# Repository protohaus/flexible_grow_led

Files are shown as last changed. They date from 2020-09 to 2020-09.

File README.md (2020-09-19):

# Flexible Grow LED

This project is the result of Sören Krusche's student research project.
The aim was to create a flexible LED light for growing plants with adjustable wavelengths.
It encompases the CAD files for the electronics and 3D printed components as well as the source code for the ESP8266 and the Node-RED flow.

## Node-RED Dashboard

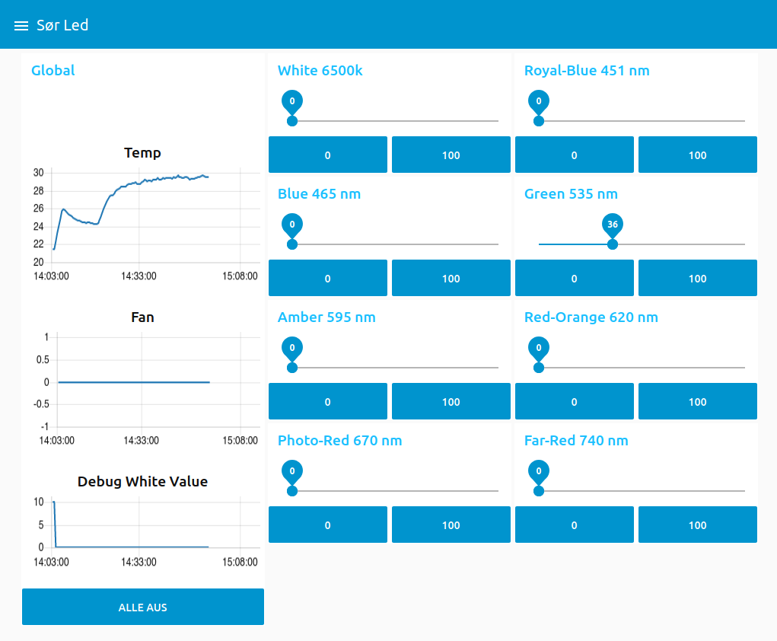
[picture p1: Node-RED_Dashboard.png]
Node-RED Dashboard


The flow can be found in the Node-RED_Flow folder.

## PCB Design

Insert PCB image

The design files can be found in the CAD/EAGLE folder.

## 3D Printed Model

Insert 3D printed model

The design files can be found in the CAD/Fusion360 folder.

## PlatformIO Project

The source code for the ESP8266 can be found in the PlatformIO folder.

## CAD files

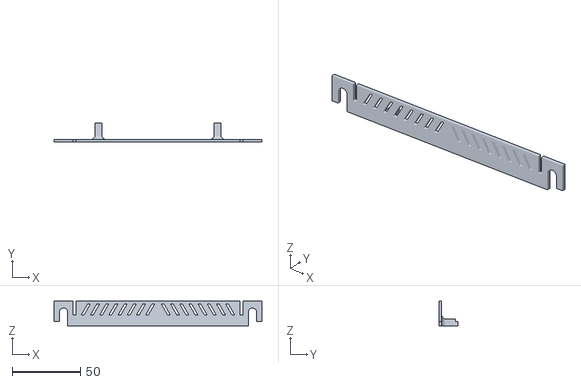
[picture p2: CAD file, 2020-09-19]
CAD/Fusion360/Halter_Back.stl
152.0 x 14.0 x 18.0

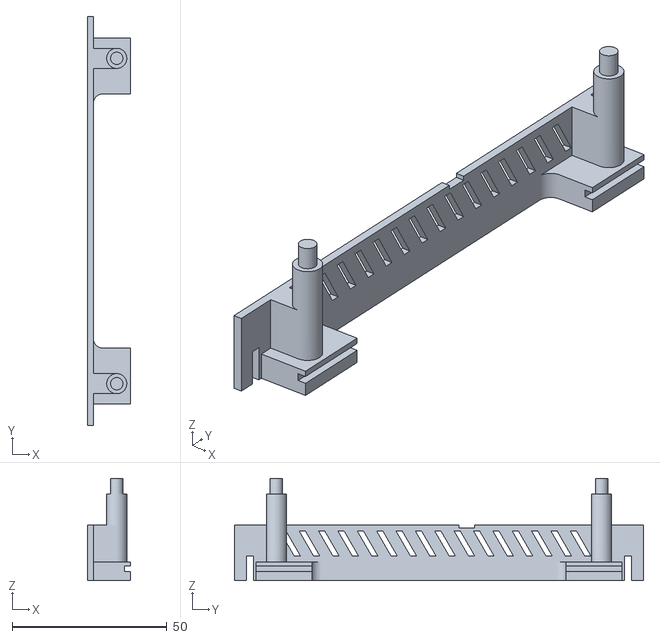
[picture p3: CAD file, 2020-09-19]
CAD/Fusion360/Halter_Right.stl
14.0 x 132.0 x 33.0

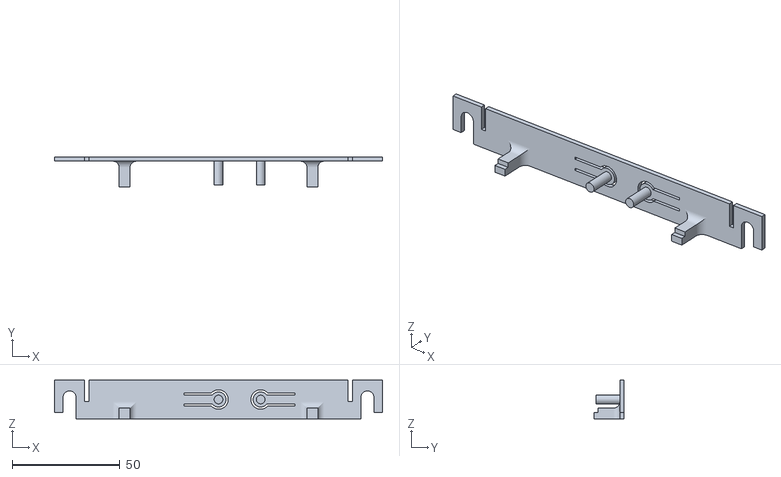
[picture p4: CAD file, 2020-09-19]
CAD/Fusion360/Halter_Front.stl
152.0 x 14.0 x 18.0

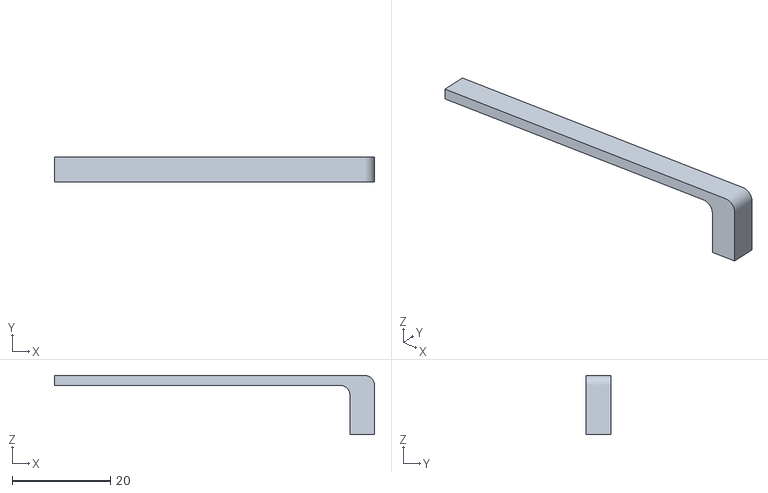
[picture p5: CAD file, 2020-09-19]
CAD/Fusion360/Lichtleiter.stl
65.0 x 5.00 x 12.0

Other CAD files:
CAD/Fusion360/Halter_Left.stl
CAD/Fusion360/Abdeckung v3.f3z
CAD/Fusion360/Halterung v11.f3z

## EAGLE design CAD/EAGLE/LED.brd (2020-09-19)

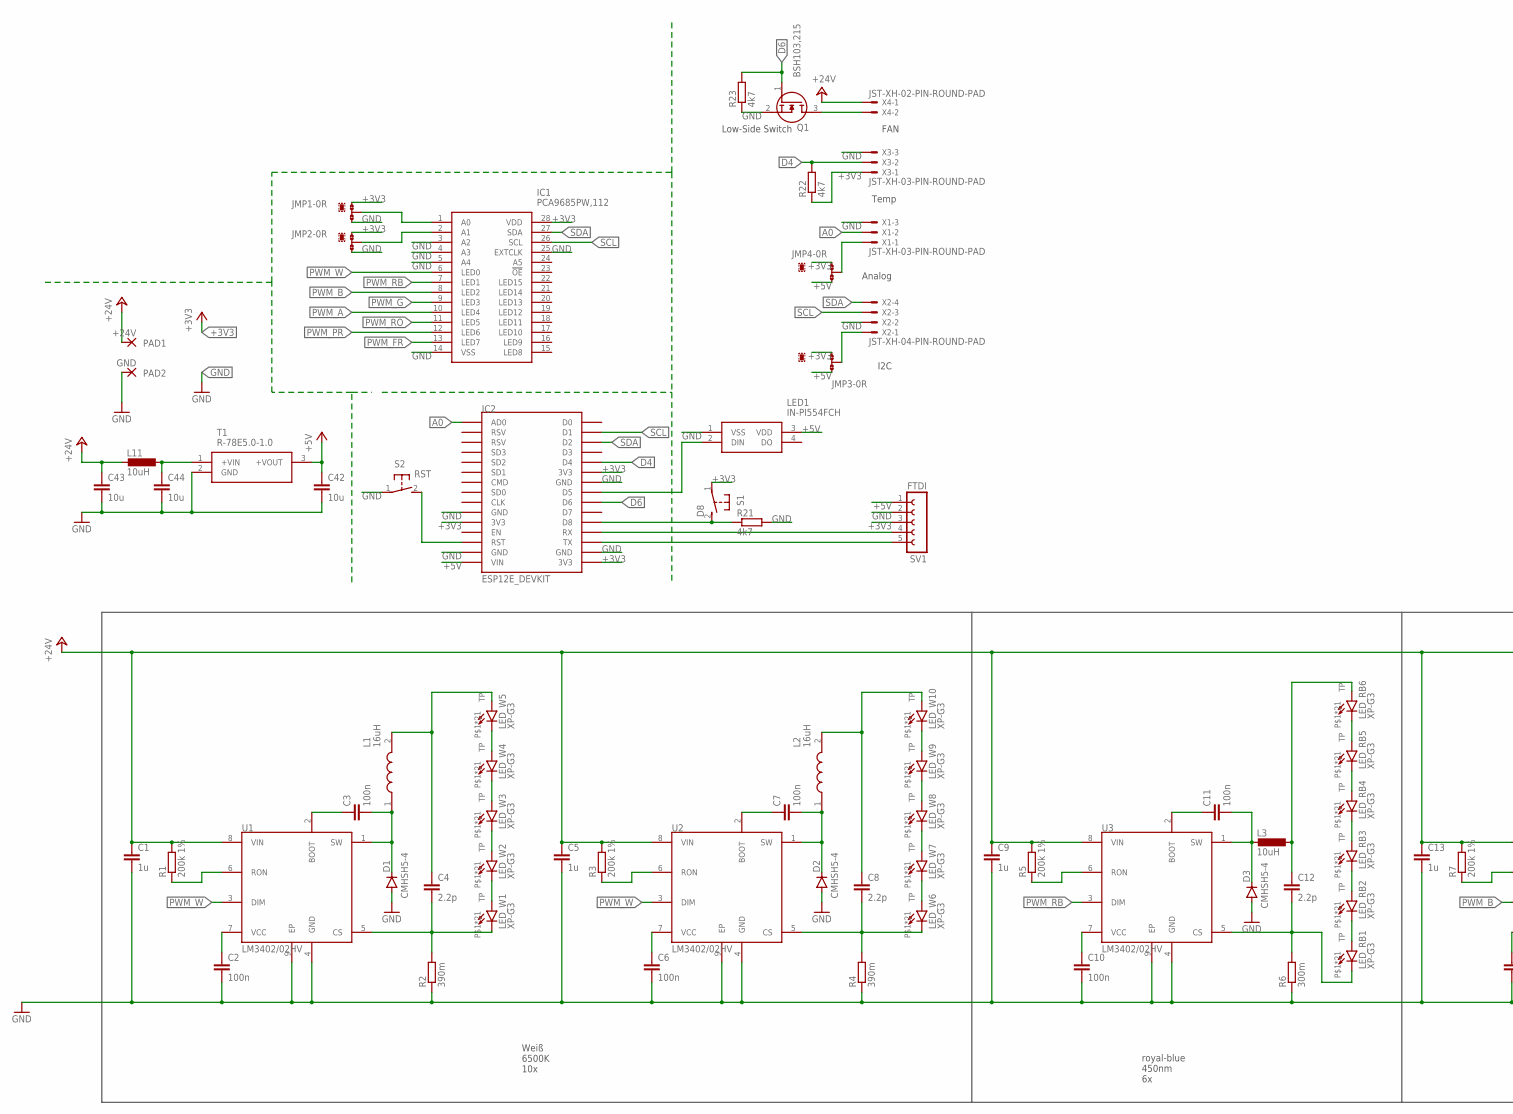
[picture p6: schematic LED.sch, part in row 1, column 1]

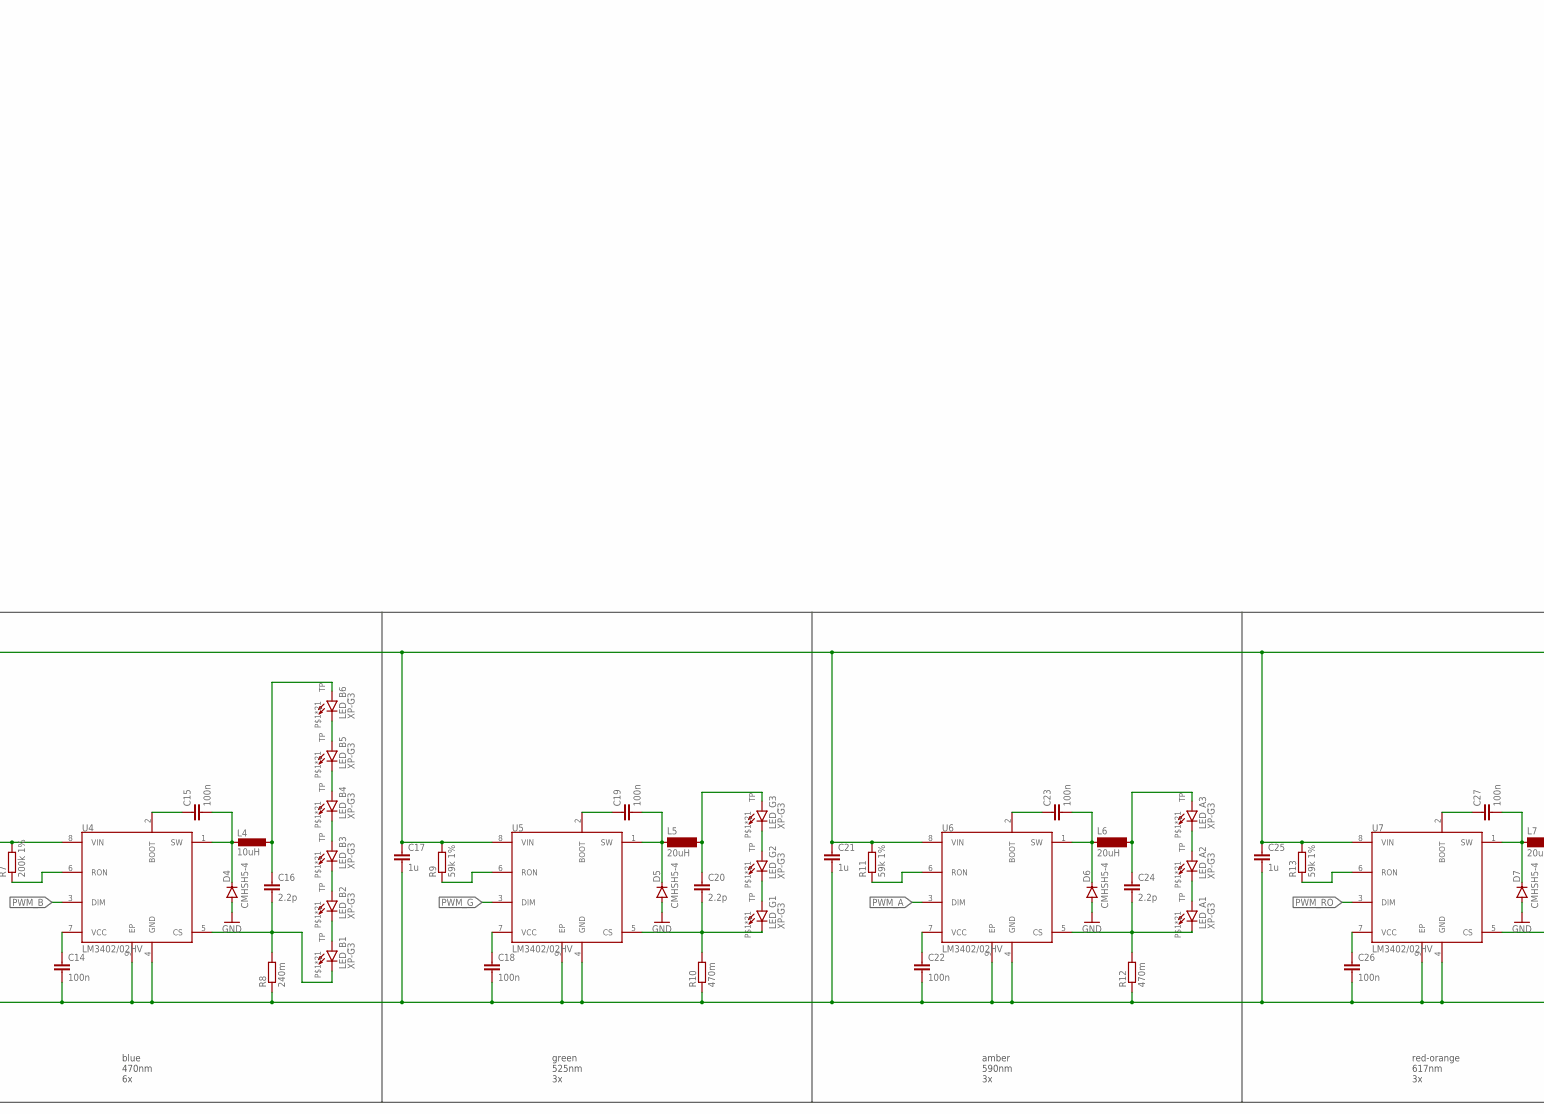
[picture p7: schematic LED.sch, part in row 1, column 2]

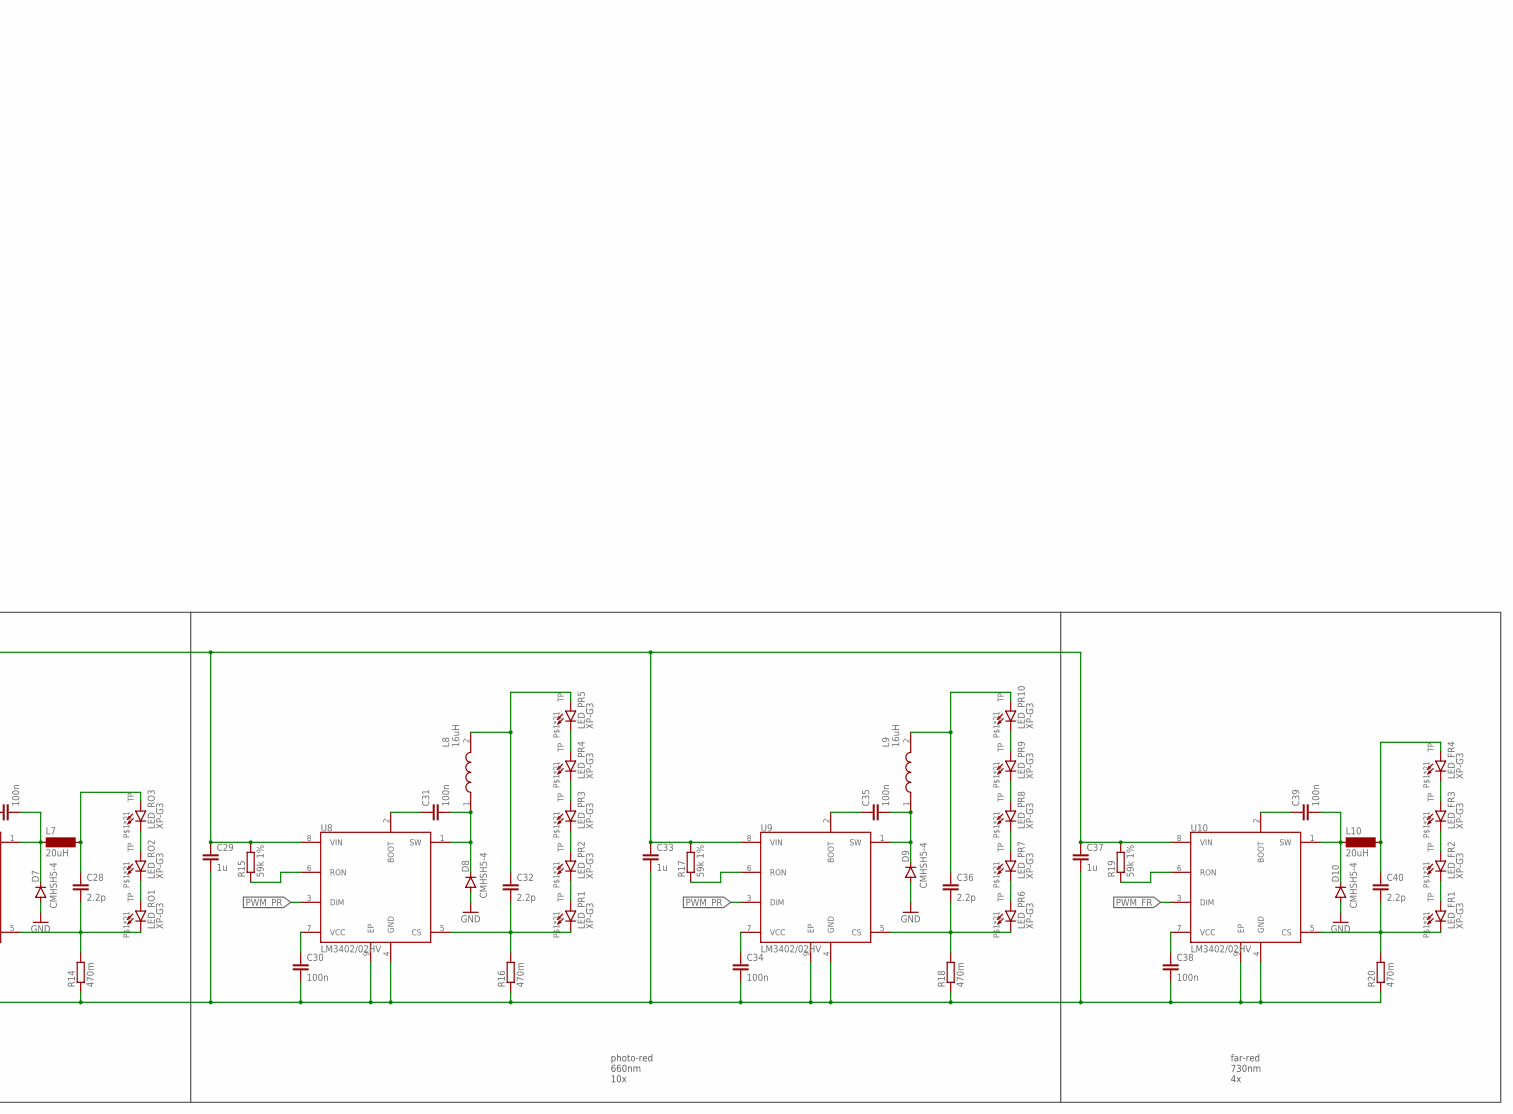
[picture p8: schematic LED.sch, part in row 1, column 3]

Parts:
C1, C5, C9, C13, C17, C21, C25, C29, C33, C37: 1u; C1206
C2, C3, C6, C7, C10, C11, C14, C15, C18, C19, C22, C23, C26, C27, C30, C31, C34, C35, C38, C39: 100n; C0805
C4, C8, C12, C16, C20, C24, C28, C32, C36, C40: 2.2p; C1206
C42, C43, C44: 10u; C1210
D1, D2, D3, D4, D5, D6, D7, D8, D9, D10: CMHSH5-4; SOD123
IC1: PCA9685PW,112; SOP65P640X110-28N
IC2: ESP12E_DEVKIT
JMP1, JMP2, JMP3, JMP4: 0R-JUMPA; A0R-JMP
L1, L2, L8, L9: 16uH; INDPM101101X680N
L3, L4, L11: 10uH; L3225M
L5, L6, L7, L10: 20uH; PF0382.223NLT
LED1: IN-PI554FCH; INPI554FCH
LED_A1, LED_A2, LED_A3: XP-G3; CREE_XLAMP
LED_B1, LED_B2, LED_B3, LED_B4, LED_B5, LED_B6: XP-G3; CREE_XLAMP
LED_FR1, LED_FR2, LED_FR3, LED_FR4: XP-G3; CREE_XLAMP
LED_G1, LED_G2, LED_G3: XP-G3; CREE_XLAMP
LED_PR1, LED_PR2, LED_PR3, LED_PR4, LED_PR5, LED_PR6, LED_PR7, LED_PR8, LED_PR9, LED_PR10: XP-G3; CREE_XLAMP
LED_RB1, LED_RB2, LED_RB3, LED_RB4, LED_RB5, LED_RB6: XP-G3; CREE_XLAMP
LED_RO1, LED_RO2, LED_RO3: XP-G3; CREE_XLAMP
LED_W1, LED_W2, LED_W3, LED_W4, LED_W5, LED_W6, LED_W7, LED_W8, LED_W9, LED_W10: XP-G3; CREE_XLAMP
PAD1: +24V; 3,81/1,4
PAD2: GND; 3,81/1,4
Q1: BSH103,215; SOT95P230X110-3N
R1, R3, R5, R7: 200k 1%; R0805
R2, R4: 390m; R0805
R6: 300m; R0805
R8: 240m; R0805
R9, R11, R13, R15, R17, R19: 59k 1%; R0805
R10, R12, R14, R16, R18, R20: 470m; R0805
R21, R22, R23: 4k7; R0805
S1: D8; B3F-31XX
S2: RST; B3F-31XX
SV1: FTDI; FE05-1
T1: R-78E5.0-1.0
U1, U2, U3, U4, U5, U6, U7, U8, U9, U10: LM3402/02HV; SOIC127P600X170-9T228N
X1, X3: JST-XH-03-PIN-ROUND-PAD; JST-XH-03-PACKAGE-ROUND-PAD
X2: JST-XH-04-PIN-ROUND-PAD; JST-XH-04-PACKAGE-ROUND-PAD
X4: JST-XH-02-PIN-ROUND-PAD; JST-XH-02-PACKAGE-ROUND-PAD

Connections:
+3V3: IC1.28 (VDD), IC2.3V3@0 (3V3), IC2.3V3@1 (3V3), IC2.3V3@2 (3V3), JMP1.1, JMP2.1, JMP3.1, JMP4.1, R22.1, S1.1, SV1.3, X3.1
+5V: C42.1, IC2.VIN, JMP3.3, JMP4.3, LED1.3 (VDD), SV1.1, T1.3 (+VOUT)
+24V: C1.1, C5.1, C9.1, C13.1, C17.1, C21.1, C25.1, C29.1, C33.1, C37.1, C43.1, L11.2, PAD1.1, R1.2, R3.2, R5.2, R7.2, R9.2, R11.2, R13.2, R15.2, R17.2, R19.2, U1.8 (VIN), U2.8 (VIN), U3.8 (VIN), U4.8 (VIN), U5.8 (VIN), U6.8 (VIN), U7.8 (VIN), U8.8 (VIN), U9.8 (VIN), U10.8 (VIN), X4.1
A0: IC2.AD0, X1.2
D4: IC2.D4, R22.2, X3.2
D6: IC2.D6, Q1.1 (G), R23.2
GND: C1.2, C2.2, C5.2, C6.2, C9.2, C10.2, C13.2, C14.2, C17.2, C18.2, C21.2, C22.2, C25.2, C26.2, C29.2, C30.2, C33.2, C34.2, C37.2, C38.2, C42.2, C43.2, C44.2, D1.A, D2.A, D3.A, D4.A, D5.A, D6.A, D7.A, D8.A, D9.A, D10.A, IC1.3 (A2), IC1.4 (A3), IC1.5 (A4), IC1.14 (VSS), IC1.25 (EXTCLK), IC2.GND@0 (GND), IC2.GND@1 (GND), IC2.GND@2 (GND), IC2.GND@3 (GND), JMP1.3, JMP2.3, LED1.1 (VSS), PAD2.1, Q1.2 (S), R2.1, R4.1, R6.1, R8.1, R10.1, R12.1, R14.1, R16.1, R18.1, R20.1, R21.2, R23.1, S2.1, SV1.2, T1.2 (GND), U1.4 (GND), U1.9 (EP), U2.4 (GND), U2.9 (EP), U3.4 (GND), U3.9 (EP), U4.4 (GND), U4.9 (EP), U5.4 (GND), U5.9 (EP), U6.4 (GND), U6.9 (EP), U7.4 (GND), U7.9 (EP), U8.4 (GND), U8.9 (EP), U9.4 (GND), U9.9 (EP), U10.4 (GND), U10.9 (EP), X1.3, X2.2, X3.3
unnamed: LED_W6.A, LED_W6.A@1 (A), LED_W7.C, LED_W7.C@1 (C)
unnamed: LED_W7.A, LED_W7.A@1 (A), LED_W8.C, LED_W8.C@1 (C)
unnamed: LED_W8.A, LED_W8.A@1 (A), LED_W9.C, LED_W9.C@1 (C)
unnamed: LED_W9.A, LED_W9.A@1 (A), LED_W10.C, LED_W10.C@1 (C)
unnamed: R3.1, U2.6 (RON)
unnamed: R1.1, U1.6 (RON)
unnamed: C3.1, U1.2 (BOOT)
unnamed: C3.2, D1.C, L1.1, U1.1 (SW)
unnamed: C2.1, U1.7 (VCC)
unnamed: LED_W1.A, LED_W1.A@1 (A), LED_W2.C, LED_W2.C@1 (C)
unnamed: LED_W2.A, LED_W2.A@1 (A), LED_W3.C, LED_W3.C@1 (C)
unnamed: LED_W3.A, LED_W3.A@1 (A), LED_W4.C, LED_W4.C@1 (C)
unnamed: LED_W4.A, LED_W4.A@1 (A), LED_W5.C, LED_W5.C@1 (C)
unnamed: LED_RB5.A, LED_RB5.A@1 (A), LED_RB6.C, LED_RB6.C@1 (C)
unnamed: C4.2, LED_W1.C, LED_W1.C@1 (C), R2.2, U1.5 (CS)
unnamed: C7.1, U2.2 (BOOT)
unnamed: C7.2, D2.C, L2.1, U2.1 (SW)
unnamed: C6.1, U2.7 (VCC)
unnamed: LED_B1.A, LED_B1.A@1 (A), LED_B2.C, LED_B2.C@1 (C)
unnamed: C8.1, L2.2, LED_W10.A, LED_W10.A@1 (A)
unnamed: LED_B2.A, LED_B2.A@1 (A), LED_B3.C, LED_B3.C@1 (C)
unnamed: LED_B3.A, LED_B3.A@1 (A), LED_B4.C, LED_B4.C@1 (C)
unnamed: LED_B4.A, LED_B4.A@1 (A), LED_B5.C, LED_B5.C@1 (C)
unnamed: LED_B5.A, LED_B5.A@1 (A), LED_B6.C, LED_B6.C@1 (C)
unnamed: IC1.1 (A0), JMP1.2
unnamed: IC2.D8, R21.1, S1.2 (S)
unnamed: C8.2, LED_W6.C, LED_W6.C@1 (C), R4.2, U2.5 (CS)
unnamed: LED_RB1.A, LED_RB1.A@1 (A), LED_RB2.C, LED_RB2.C@1 (C)
unnamed: LED_RB2.A, LED_RB2.A@1 (A), LED_RB3.C, LED_RB3.C@1 (C)
unnamed: LED_RB3.A, LED_RB3.A@1 (A), LED_RB4.C, LED_RB4.C@1 (C)
unnamed: LED_RB4.A, LED_RB4.A@1 (A), LED_RB5.C, LED_RB5.C@1 (C)
unnamed: R5.1, U3.6 (RON)
unnamed: C11.1, U3.2 (BOOT)
unnamed: C11.2, D3.C, L3.2, U3.1 (SW)
unnamed: C10.1, U3.7 (VCC)
unnamed: C12.1, L3.1, LED_RB6.A, LED_RB6.A@1 (A)
unnamed: C12.2, LED_RB1.C, LED_RB1.C@1 (C), R6.2, U3.5 (CS)
unnamed: C44.1, L11.1, T1.1 (+VIN)
unnamed: IC1.2 (A1), JMP2.2
unnamed: JMP3.2, X2.1
unnamed: IC2.RST, S2.2 (S)
unnamed: JMP4.2, X1.1
unnamed: IC2.D5, LED1.2 (DIN)
unnamed: IC2.RX, SV1.4
unnamed: IC2.TX, SV1.5
unnamed: Q1.3 (D), X4.2
unnamed: R7.1, U4.6 (RON)
unnamed: C15.1, U4.2 (BOOT)
unnamed: C15.2, D4.C, L4.2, U4.1 (SW)
unnamed: C14.1, U4.7 (VCC)
unnamed: C16.1, L4.1, LED_B6.A, LED_B6.A@1 (A)
unnamed: C16.2, LED_B1.C, LED_B1.C@1 (C), R8.2, U4.5 (CS)
unnamed: LED_G1.A, LED_G1.A@1 (A), LED_G2.C, LED_G2.C@1 (C)
unnamed: LED_G2.A, LED_G2.A@1 (A), LED_G3.C, LED_G3.C@1 (C)
unnamed: R9.1, U5.6 (RON)
unnamed: C19.1, U5.2 (BOOT)
unnamed: C19.2, D5.C, L5.P0, U5.1 (SW)
unnamed: C18.1, U5.7 (VCC)
unnamed: C20.1, L5.P1, LED_G3.A, LED_G3.A@1 (A)
unnamed: C20.2, LED_G1.C, LED_G1.C@1 (C), R10.2, U5.5 (CS)
unnamed: LED_A1.A, LED_A1.A@1 (A), LED_A2.C, LED_A2.C@1 (C)
unnamed: LED_A2.A, LED_A2.A@1 (A), LED_A3.C, LED_A3.C@1 (C)
unnamed: R11.1, U6.6 (RON)
unnamed: C23.1, U6.2 (BOOT)
unnamed: C23.2, D6.C, L6.P0, U6.1 (SW)
unnamed: C22.1, U6.7 (VCC)
unnamed: C24.1, L6.P1, LED_A3.A, LED_A3.A@1 (A)
unnamed: C24.2, LED_A1.C, LED_A1.C@1 (C), R12.2, U6.5 (CS)
unnamed: LED_RO1.A, LED_RO1.A@1 (A), LED_RO2.C, LED_RO2.C@1 (C)
unnamed: LED_RO2.A, LED_RO2.A@1 (A), LED_RO3.C, LED_RO3.C@1 (C)
unnamed: R13.1, U7.6 (RON)
unnamed: C27.1, U7.2 (BOOT)
unnamed: C27.2, D7.C, L7.P0, U7.1 (SW)
unnamed: C26.1, U7.7 (VCC)
unnamed: C28.1, L7.P1, LED_RO3.A, LED_RO3.A@1 (A)
unnamed: C28.2, LED_RO1.C, LED_RO1.C@1 (C), R14.2, U7.5 (CS)
unnamed: LED_PR1.A, LED_PR1.A@1 (A), LED_PR2.C, LED_PR2.C@1 (C)
unnamed: LED_PR2.A, LED_PR2.A@1 (A), LED_PR3.C, LED_PR3.C@1 (C)
unnamed: LED_PR3.A, LED_PR3.A@1 (A), LED_PR4.C, LED_PR4.C@1 (C)
unnamed: LED_PR4.A, LED_PR4.A@1 (A), LED_PR5.C, LED_PR5.C@1 (C)
unnamed: R15.1, U8.6 (RON)
unnamed: C31.1, U8.2 (BOOT)
unnamed: C31.2, D8.C, L8.1, U8.1 (SW)
unnamed: C30.1, U8.7 (VCC)
unnamed: C32.1, L8.2, LED_PR5.A, LED_PR5.A@1 (A)
unnamed: C32.2, LED_PR1.C, LED_PR1.C@1 (C), R16.2, U8.5 (CS)
unnamed: LED_PR6.A, LED_PR6.A@1 (A), LED_PR7.C, LED_PR7.C@1 (C)
unnamed: LED_PR7.A, LED_PR7.A@1 (A), LED_PR8.C, LED_PR8.C@1 (C)
unnamed: LED_PR8.A, LED_PR8.A@1 (A), LED_PR9.C, LED_PR9.C@1 (C)
unnamed: LED_PR9.A, LED_PR9.A@1 (A), LED_PR10.C, LED_PR10.C@1 (C)
unnamed: R17.1, U9.6 (RON)
unnamed: C35.1, U9.2 (BOOT)
unnamed: C35.2, D9.C, L9.1, U9.1 (SW)
unnamed: C34.1, U9.7 (VCC)
unnamed: C36.1, L9.2, LED_PR10.A, LED_PR10.A@1 (A)
unnamed: C36.2, LED_PR6.C, LED_PR6.C@1 (C), R18.2, U9.5 (CS)
unnamed: LED_FR1.A, LED_FR1.A@1 (A), LED_FR2.C, LED_FR2.C@1 (C)
unnamed: LED_FR2.A, LED_FR2.A@1 (A), LED_FR3.C, LED_FR3.C@1 (C)
unnamed: LED_FR3.A, LED_FR3.A@1 (A), LED_FR4.C, LED_FR4.C@1 (C)
unnamed: R19.1, U10.6 (RON)
unnamed: C39.1, U10.2 (BOOT)
unnamed: C39.2, D10.C, L10.P0, U10.1 (SW)
unnamed: C38.1, U10.7 (VCC)
unnamed: C40.1, L10.P1, LED_FR4.A, LED_FR4.A@1 (A)
unnamed: C40.2, LED_FR1.C, LED_FR1.C@1 (C), R20.2, U10.5 (CS)
unnamed: C4.1, L1.2, LED_W5.A, LED_W5.A@1 (A)
PWM_A: IC1.10 (LED4), U6.3 (DIM)
PWM_B: IC1.8 (LED2), U4.3 (DIM)
PWM_FR: IC1.13 (LED7), U10.3 (DIM)
PWM_G: IC1.9 (LED3), U5.3 (DIM)
PWM_PR: IC1.12 (LED6), U8.3 (DIM), U9.3 (DIM)
PWM_RB: IC1.7 (LED1), U3.3 (DIM)
PWM_RO: IC1.11 (LED5), U7.3 (DIM)
PWM_W: IC1.6 (LED0), U1.3 (DIM), U2.3 (DIM)
SCL: IC1.26 (SCL), IC2.D1, X2.3
SDA: IC1.27 (SDA), IC2.D2, X2.4

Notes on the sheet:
Weiß 6500K 10x
royal-blue 450nm 6x
blue 470nm 6x
green 525nm 3x
amber 590nm 3x
red-orange 617nm 3x
photo-red 660nm 10x
far-red 730nm 4x
I2C
Analog
Temp
FAN
Low-Side Switch

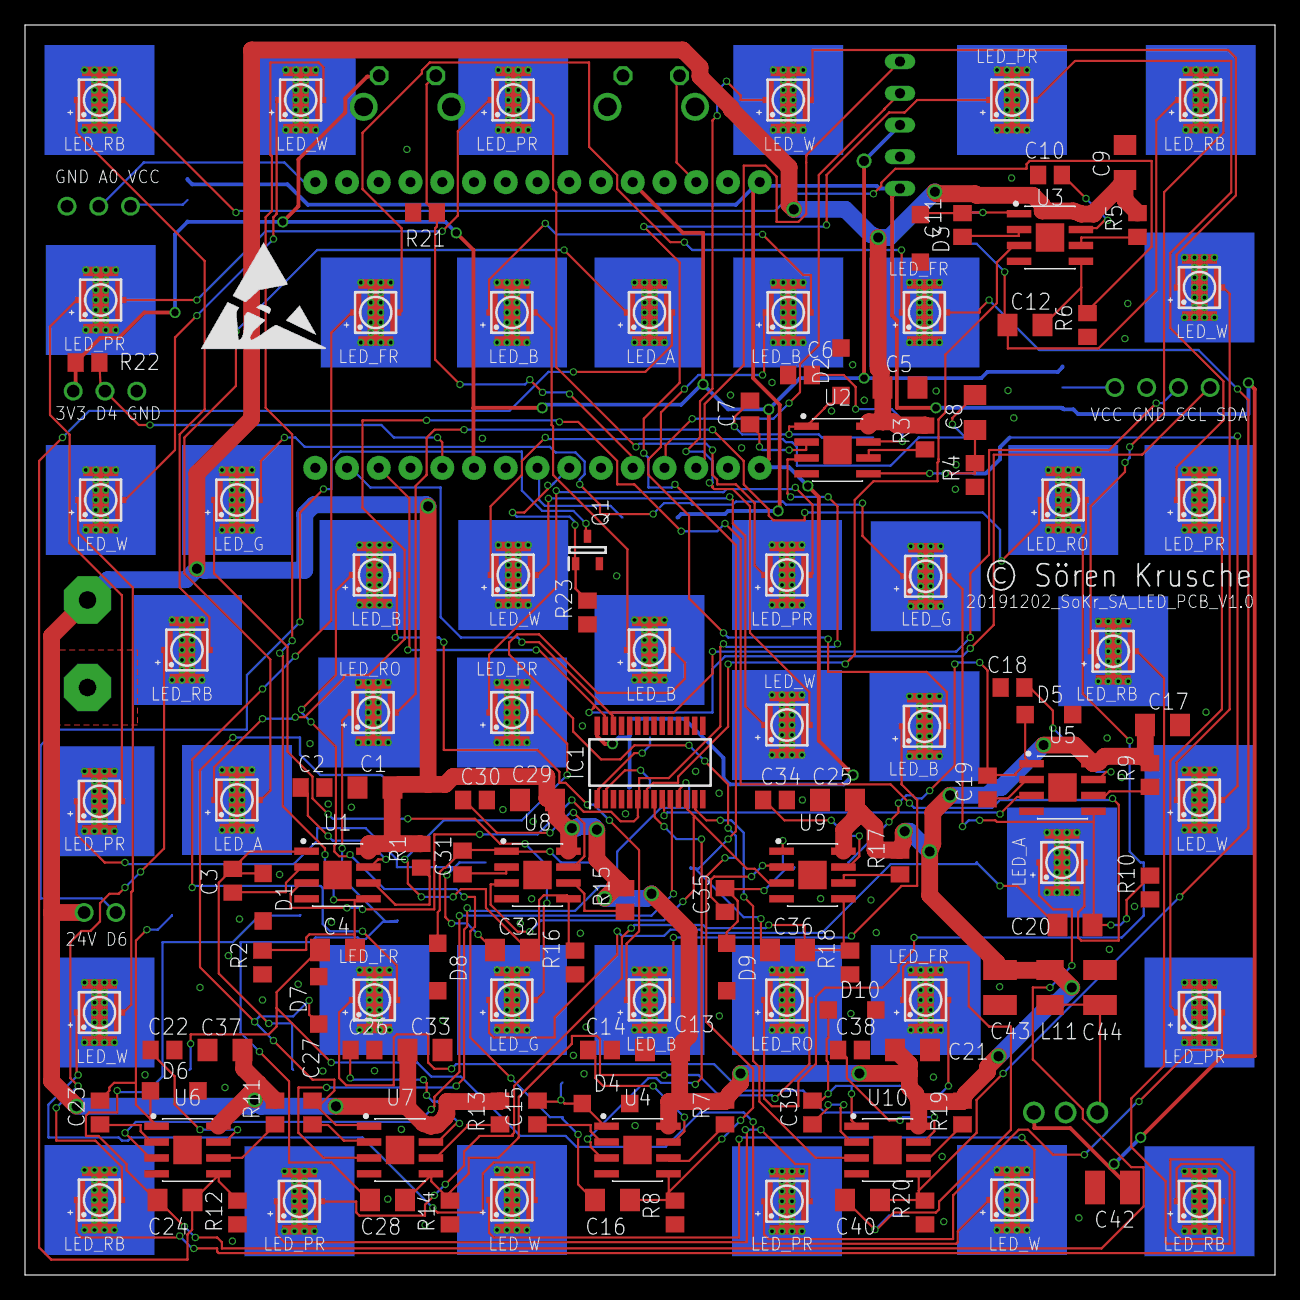
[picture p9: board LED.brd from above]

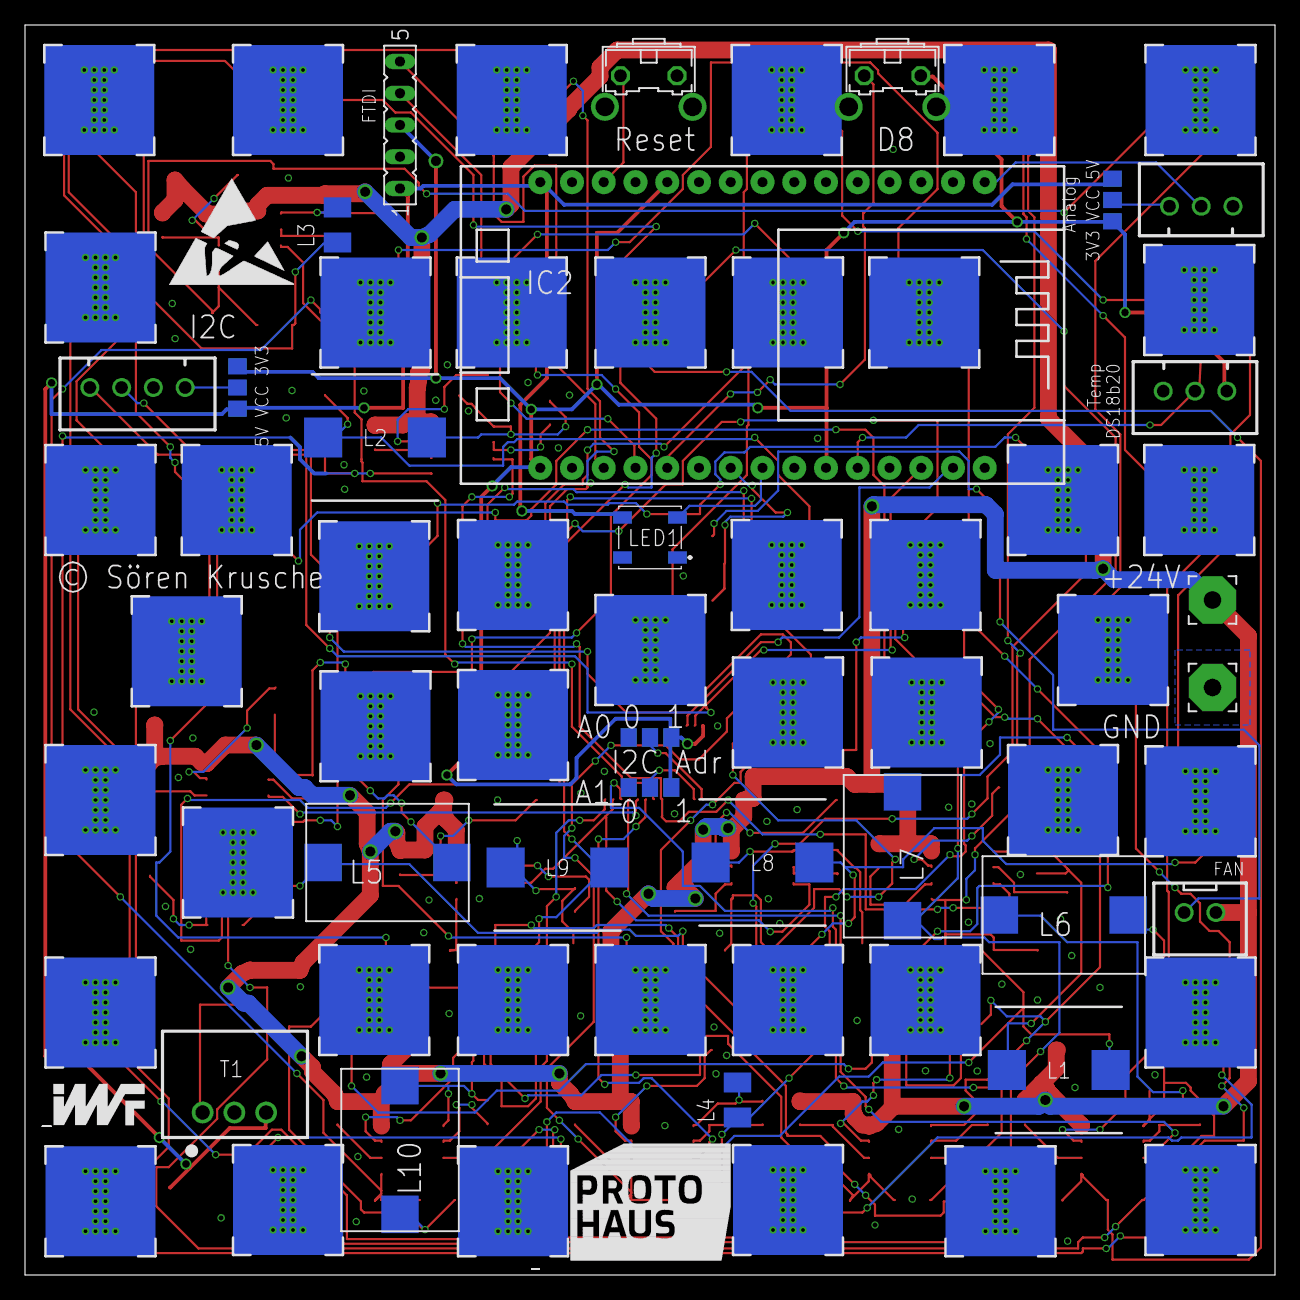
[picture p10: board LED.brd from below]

Board: 2 copper layers, 100.0 x 100.0 mm, 162 parts (27 on the bottom side), 123 nets.

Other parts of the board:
U$1, U$2: ESD_10.00

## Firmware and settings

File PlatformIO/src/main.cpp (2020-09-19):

#include <Arduino.h>
#include <PCA9685.h>
#include <Wire.h>
#include <ArduinoJson.h>
#include <ESP8266WiFi.h>
#include <ESP8266mDNS.h>
#include <WiFiUdp.h>
#include <ArduinoOTA.h>
#include <PubSubClient.h>
#include <FastLED.h>
#include <Bounce2.h> 
#include <OneWire.h>
#include <DallasTemperature.h>

//================================Settings================================

// PCA9685 PWM Generator settings
const int fI2c_adr = 0x43;
float fPwm_freq = 800.0;
PCA9685 pwm_gen = PCA9685(fI2c_adr, PCA9685_MODE_N_DRIVER, fPwm_freq);

//JSON Parser
StaticJsonDocument<200> doc_in;
StaticJsonDocument<2048> doc_out;

// Wifi/MQTT settings
const char *cUuid = "e49ee006-b5f1-4a57-813b-dd339f91ace6";

// Update these with values suitable for your network.
const char *ssid = "ssid";
const char *password = "password";
const char *mqtt_server = "ip or adress";

WiFiClient espClient;
PubSubClient client(espClient);

//Info-LED Settings
#define NUM_LEDS 1
#define DATA_PIN 5
CRGB leds[NUM_LEDS];

// Temp Sensor DS18b20
#define ONE_WIRE_BUS D4
OneWire oneWire(ONE_WIRE_BUS);
DallasTemperature sensors(&oneWire);
float fTemp = 20.0;

// Fan
uint16_t FanSpeed = 0;
float fUpperLimit = 0;
float fLowerLimit = 0;

// Button
Bounce debouncer = Bounce();
bool bButton = false;
bool bButton_old = false;

// Timer Leselampe
unsigned long previousMillis_whiteMode = 0;
const long interval_whiteMode = 60000; //60s
bool bActive = false;
// Timer MQTT Update
unsigned long previousMillis_MQTT = 0;
const long interval_MQTT = 300000; //300s
// Timer Temp + Fan Update
unsigned long previousMillis_Fan = 0;
const long interval_Fan = 30000; //30s

//================================LED Functions================================
void set_LEDs(String sColor, float fBrightness)
{
  uint8_t iColor = 15;
  if (sColor == "white")
    iColor = 0;
  if (sColor == "royal_blue")
    iColor = 1;
  if (sColor == "blue")
    iColor = 2;
  if (sColor == "green")
    iColor = 3;
  if (sColor == "amber")
    iColor = 4;
  if (sColor == "red_orange")
    iColor = 5;
  if (sColor == "photo_red")
    iColor = 6;
  if (sColor == "far_red")
    iColor = 7;
  if (!bButton)
  {
    int iBrightness = map(fBrightness, 0.0, 100.0, 0, 4095);
    pwm_gen.getPin(iColor).setValueAndWrite(iBrightness);
  }
}

//================================WiFi/MQTT Functions================================
void setup_wifi()
{

  delay(10);
  // We start by connecting to a WiFi network
  Serial.println();
  Serial.print("Connecting to ");
  Serial.println(ssid);

  WiFi.begin(ssid, password);
  WiFi.hostname("LED-Panel_ESP");

  while (WiFi.status() != WL_CONNECTED)
  {
    delay(500);
    Serial.print(".");
  }

  Serial.println("");
  Serial.println("WiFi connected");
  Serial.println("IP address: ");
  Serial.println(WiFi.localIP());
}

void wifi_check()
{
  int wifi_retry = 0;
  while (WiFi.status() != WL_CONNECTED && wifi_retry < 5)
  {
    wifi_retry++;
    Serial.println("WiFi not connected. Try to reconnect");
    WiFi.disconnect();
    WiFi.mode(WIFI_OFF);
    WiFi.mode(WIFI_STA);
    WiFi.begin(ssid, password);
    WiFi.hostname("LED-Panel_ESP");
  }
  if (wifi_retry >= 5)
  {
    Serial.println("\nReboot");
    ESP.restart();
  }
}
// MQTT
void callback(char *topic, byte *payload, int length)
{

  DeserializationError error = deserializeJson(doc_in, payload, length);
  // Test if parsing succeeds.
  if (error)
  {
    Serial.print(F("deserializeJson() failed: "));
    Serial.println(error.c_str());
    return;
  }

  //serializeJsonPretty(doc_in, Serial);
  set_LEDs(doc_in["enable"]["color"], doc_in["enable"]["power_percent"]);
}

void reconnect()
{
  // Loop until we're reconnected
  while (!client.connected())
  {
    Serial.print("Attempting MQTT connection...");
    // Create a random client ID
    String clientId = "ESP8266Client-e49ee006-b5f1-4a57-813b-dd339f91ace6";
    // Attempt to connect
    if (client.connect(clientId.c_str()))
    {
      Serial.println("connected");
      // ... and resubscribe
      client.subscribe("action/e49ee006-b5f1-4a57-813b-dd339f91ace6/led");
    }
    else
    {
      Serial.print("failed, rc=");
      Serial.print(client.state());
      Serial.println(" try again in 5 seconds");
      // Wait 5 seconds before retrying
      delay(5000);
    }
  }
}

//================================Setup & Loop================================
void setup()
{
  // setup GPIOs
  pinMode(D6, OUTPUT);

  // Info-LED and Fan Test
  FastLED.addLeds<WS2812B, DATA_PIN, GRB>(leds, NUM_LEDS); //Info-LED
  leds[0] = CRGB::Red;
  FastLED.show();
  analogWrite(D6, 512); //Fan 10%
  delay(500);
  leds[0] = CRGB::Green;
  FastLED.show();
  delay(500);
  leds[0] = CRGB::Blue;
  FastLED.show();
  delay(500);
  leds[0] = CRGB::Black;
  FastLED.show();
  analogWrite(D6, 0); //Fan 0%

  debouncer.attach(D8);
  debouncer.interval(5); // interval in ms

  // initialize serial for debug output
  Serial.begin(9600);
  // initialize TwoWire communication
  Wire.begin();
  // setup the PCA9685
  pwm_gen.setup();

  // reset all LEDs
  for (uint8_t i = 0; i < 15; i++)
  {
    pwm_gen.getPin(i).setValueAndWrite(10);
  }

  // setup Temp-Sensor
  sensors.begin();

  setup_wifi();
  /*__________________OTA Begin_______________*/

  ArduinoOTA.setPassword("admin");
  ArduinoOTA.onStart([]() {
    String type;
    if (ArduinoOTA.getCommand() == U_FLASH)
    {
      type = "sketch";
    }
    else
    { // U_FS
      type = "filesystem";
    }

    // NOTE: if updating FS this would be the place to unmount FS using FS.end()
    Serial.println("Start updating " + type);
  });
  ArduinoOTA.onEnd([]() {
    Serial.println("\nEnd");
  });
  ArduinoOTA.onProgress([](unsigned int progress, unsigned int total) {
    Serial.printf("Progress: %u%%\r", (progress / (total / 100)));
  });
  ArduinoOTA.onError([](ota_error_t error) {
    Serial.printf("Error[%u]: ", error);
    if (error == OTA_AUTH_ERROR)
    {
      Serial.println("Auth Failed");
    }
    else if (error == OTA_BEGIN_ERROR)
    {
      Serial.println("Begin Failed");
    }
    else if (error == OTA_CONNECT_ERROR)
    {
      Serial.println("Connect Failed");
    }
    else if (error == OTA_RECEIVE_ERROR)
    {
      Serial.println("Receive Failed");
    }
    else if (error == OTA_END_ERROR)
    {
      Serial.println("End Failed");
    }
  });
  ArduinoOTA.begin();
  /*__________________OTA END_______________*/
  client.setServer(mqtt_server, 1883);
  client.setCallback(callback);
}

void loop()
{
  wifi_check();
  ArduinoOTA.handle();

  unsigned long currentMillis = millis();

  if (!client.connected())
  {
    reconnect();
  }
  client.loop();

  debouncer.update();
  if (debouncer.rose())
  {
    bButton = !bButton;
  }

  // Leselampe D8
  if (bButton && !bActive)
  {
    // White for 60s
    for (uint8_t i = 1; i < 15; i++) //All Black
    {
      pwm_gen.getPin(i).setValueAndWrite(0);
    }
    pwm_gen.getPin(0).setValueAndWrite(2048); // White 50%
    leds[0] = CRGB::White;
    FastLED.show();
    bActive = true;
  }

  // Restore Old Values
  if (currentMillis - previousMillis_whiteMode >= interval_whiteMode || (!bButton && bButton_old))
  {
    previousMillis_whiteMode = currentMillis;
    bButton = false;
    bActive = false;
    client.publish("action/e49ee006-b5f1-4a57-813b-dd339f91ace6/request_update", "1");

    leds[0] = CRGB::Black;
    FastLED.show();
  }

  // Normal MQTT Update
  if (currentMillis - previousMillis_MQTT >= interval_MQTT && !bButton)
  {
    previousMillis_MQTT = currentMillis;

    client.publish("action/e49ee006-b5f1-4a57-813b-dd339f91ace6/request_update", "1"); //Send Update Request
  }

  // Normal int Update
  if (currentMillis - previousMillis_Fan >= interval_Fan)
  {
    previousMillis_Fan = currentMillis;

    // read Temp-Sensor
    sensors.requestTemperatures();
    fTemp = sensors.getTempCByIndex(0);
    Serial.println(fTemp);

    // Lüfterdrehzahl anpassen
    if (fTemp > 1 && fTemp < 30)
      FanSpeed = 0;

    else if (fTemp >= 30 && fTemp < 40)
      FanSpeed = map(fTemp, 30, 40, 419, 1023);

    else
      FanSpeed = 1023;

    analogWrite(D6, FanSpeed); // Set Fan Speed

    // Json doc_out für MQTT State
    //String sHostname = WiFi.hostname();
    //doc_out["Hostname"] = sHostname.c_str();
    //String sIpAdress = WiFi.localIP().toString();
    //doc_out["WLAN_IP"] = sIpAdress.c_str();
    doc_out["Temp"] = fTemp;
    doc_out["Fan"] = FanSpeed;

    char sTemp[6];
    dtostrf(fTemp, 2, 2, sTemp);
    client.publish("action/e49ee006-b5f1-4a57-813b-dd339f91ace6/temp", sTemp); //Send Temp

    char sFanSpeed[4];
    dtostrf(FanSpeed, 4, 0, sFanSpeed);
    client.publish("action/e49ee006-b5f1-4a57-813b-dd339f91ace6/fan", sFanSpeed); //Send Fan Speed

    // debug

    char sWhiteValue[4];
    dtostrf(pwm_gen.getPin(0).getValue(), 4, 0, sWhiteValue);
    client.publish("action/e49ee006-b5f1-4a57-813b-dd339f91ace6/debug_white", sWhiteValue); //Send White Value
    doc_out["debug_white_Value"] = pwm_gen.getPin(0).getValue();

   /* byte error;
    Wire.beginTransmission(112);
    error = Wire.endTransmission();

    if (error == 0)
      doc_out["i2c"] = true;
    else
      doc_out["i2c"] = false;
*/
    String sJsonOut;
    serializeJson(doc_out, sJsonOut);
    client.publish("action/e49ee006-b5f1-4a57-813b-dd339f91ace6/debug", sJsonOut.c_str());
    // debug_end
  }

  bButton_old = bButton;
}

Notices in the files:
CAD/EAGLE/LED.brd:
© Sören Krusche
